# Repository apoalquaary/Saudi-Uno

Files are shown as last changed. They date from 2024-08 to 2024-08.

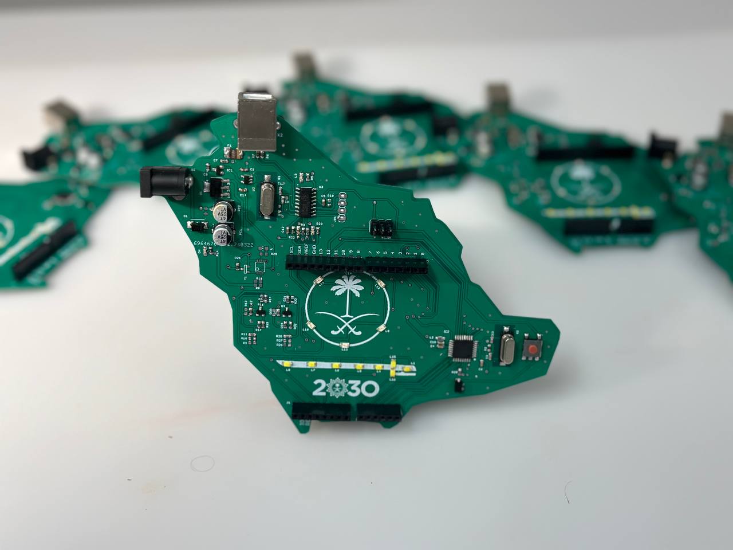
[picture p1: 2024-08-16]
images/photo_5908730412442698921_y.jpg

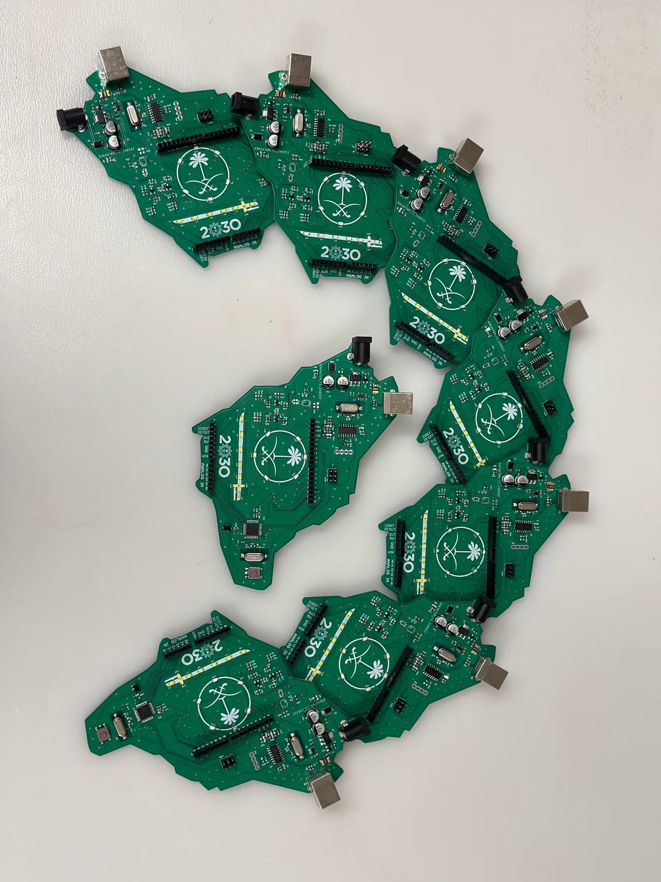
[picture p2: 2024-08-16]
images/photo_5908730412442698924_y.jpg

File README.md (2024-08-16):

<h1>Saudi UNO PCB Project</h1>
<p>This repository hosts the PCB design files for the Saudi UNO, an Arduino UNO-compatible device designed in the shape of the Saudi map. It's intended primarily for educational use in electronics and microcontroller programming.</p>

<h2>Project Overview</h2>
<p>The Saudi UNO is a unique Arduino UNO variant, customized to reflect the geographic outline of Saudi Arabia. It serves as an educational tool to engage students in learning about electronics design and practical PCB layout techniques.</p>

<h2>Files Included</h2>
<ul>
    <li><strong>Gerber Files:</strong> Contains all necessary manufacturing data for the PCB.</li>
    <li><strong>Schematic Files:</strong> Electronic schematics detailing component placement and connections.</li>
    <li><strong>Assembly Drawings:</strong> Helpful for visualizing component placement during the soldering process.</li>
    <li><strong>Bill of Materials (BOM):</strong> A comprehensive list of all components required to build the Saudi UNO.</li>
</ul>

<image src="https://github.com/apoalquaary/Saudi-Uno/blob/main/images/photo_5908730412442698918_y.jpg">
<image src="https://github.com/apoalquaary/Saudi-Uno/blob/main/images/photo_5908730412442698917_y.jpg">
<image src="https://github.com/apoalquaary/Saudi-Uno/blob/main/images/photo_5908730412442698921_y.jpg">
<image src="https://github.com/apoalquaary/Saudi-Uno/blob/main/images/photo_5908730412442698924_y.jpg">
<image src="https://github.com/apoalquaary/Saudi-Uno/blob/main/images/photo_5908730412442698913_y.jpg">

<h2>How to Use</h2>
<p>To use these files:</p>
<ol>
    <li>Download the desired files from the repository.</li>
    <li>Contact a PCB manufacturer and provide them with the Gerber files for production.</li>
    <li>Refer to the assembly drawings and BOM for assembling the PCB once manufactured.</li>
</ol>

<h2>Prerequisites</h2>
<p>You will need access to PCB manufacturing services and basic soldering tools to assemble the board. Familiarity with electronic components and soldering is recommended.</p>

<h2>Contributing</h2>
<p>If you have suggestions for improving the design, or have developed a variant of the Saudi UNO, please consider submitting a pull request. See <code>CONTRIBUTING.md</code> for more details on how to contribute.</p>

<h2>License</h2>
<p>This project is distributed under the Saudi UNO Non-Commercial License, which allows for non-commercial use such as academic and personal learning free of charge. Commercial use requires prior approval. For complete terms, see the <code>LICENSE</code> file.</p>

<h2>Contact</h2>
<p>For inquiries about commercial use or further questions, please reach out via [Your Email Address].</p>

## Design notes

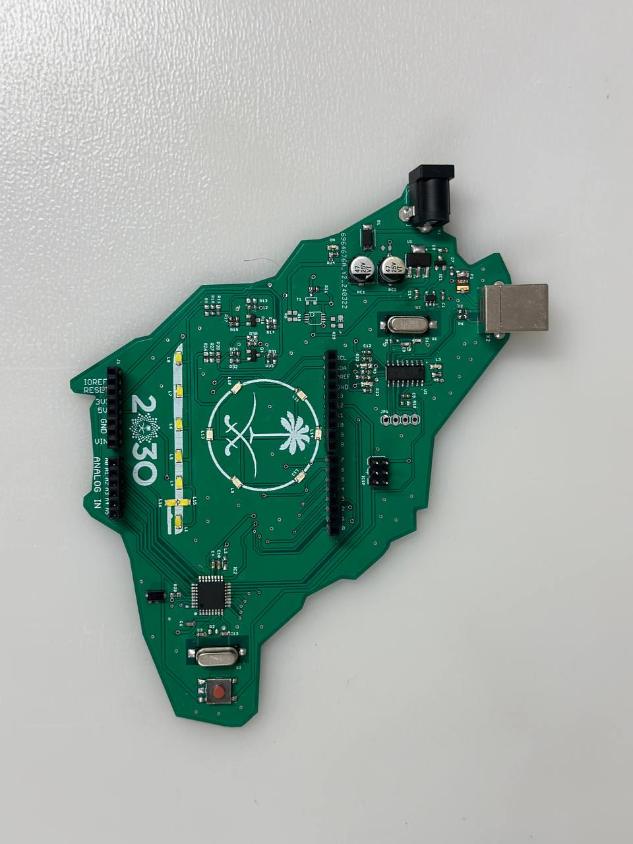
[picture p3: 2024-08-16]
images/photo_5908730412442698917_y.jpg

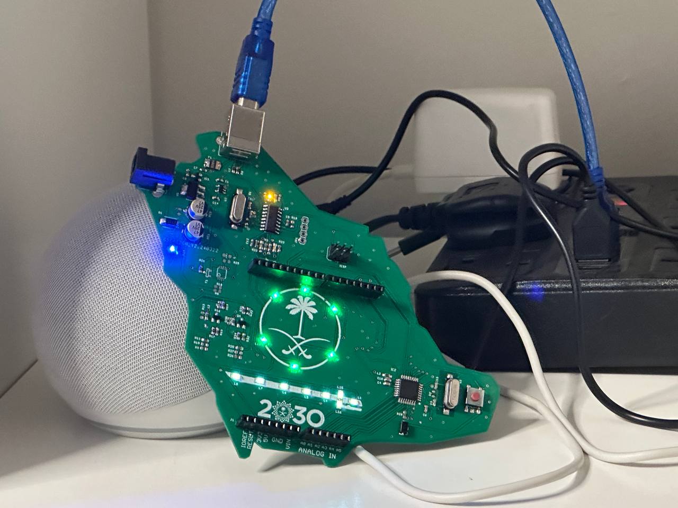
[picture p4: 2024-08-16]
images/photo_5908730412442698913_y.jpg

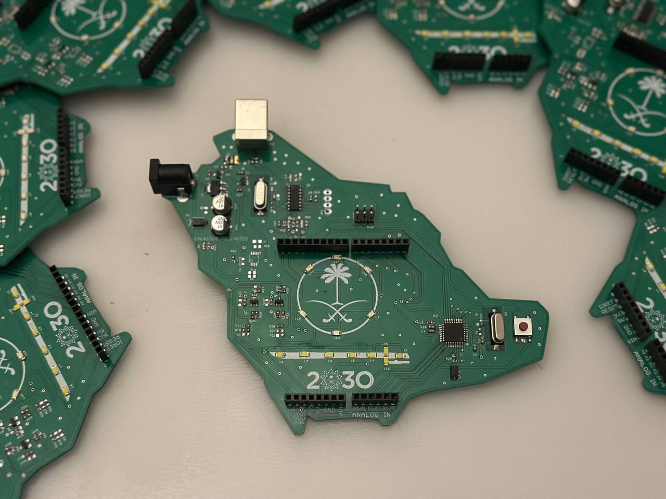
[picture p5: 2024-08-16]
images/photo_5908730412442698918_y.jpg

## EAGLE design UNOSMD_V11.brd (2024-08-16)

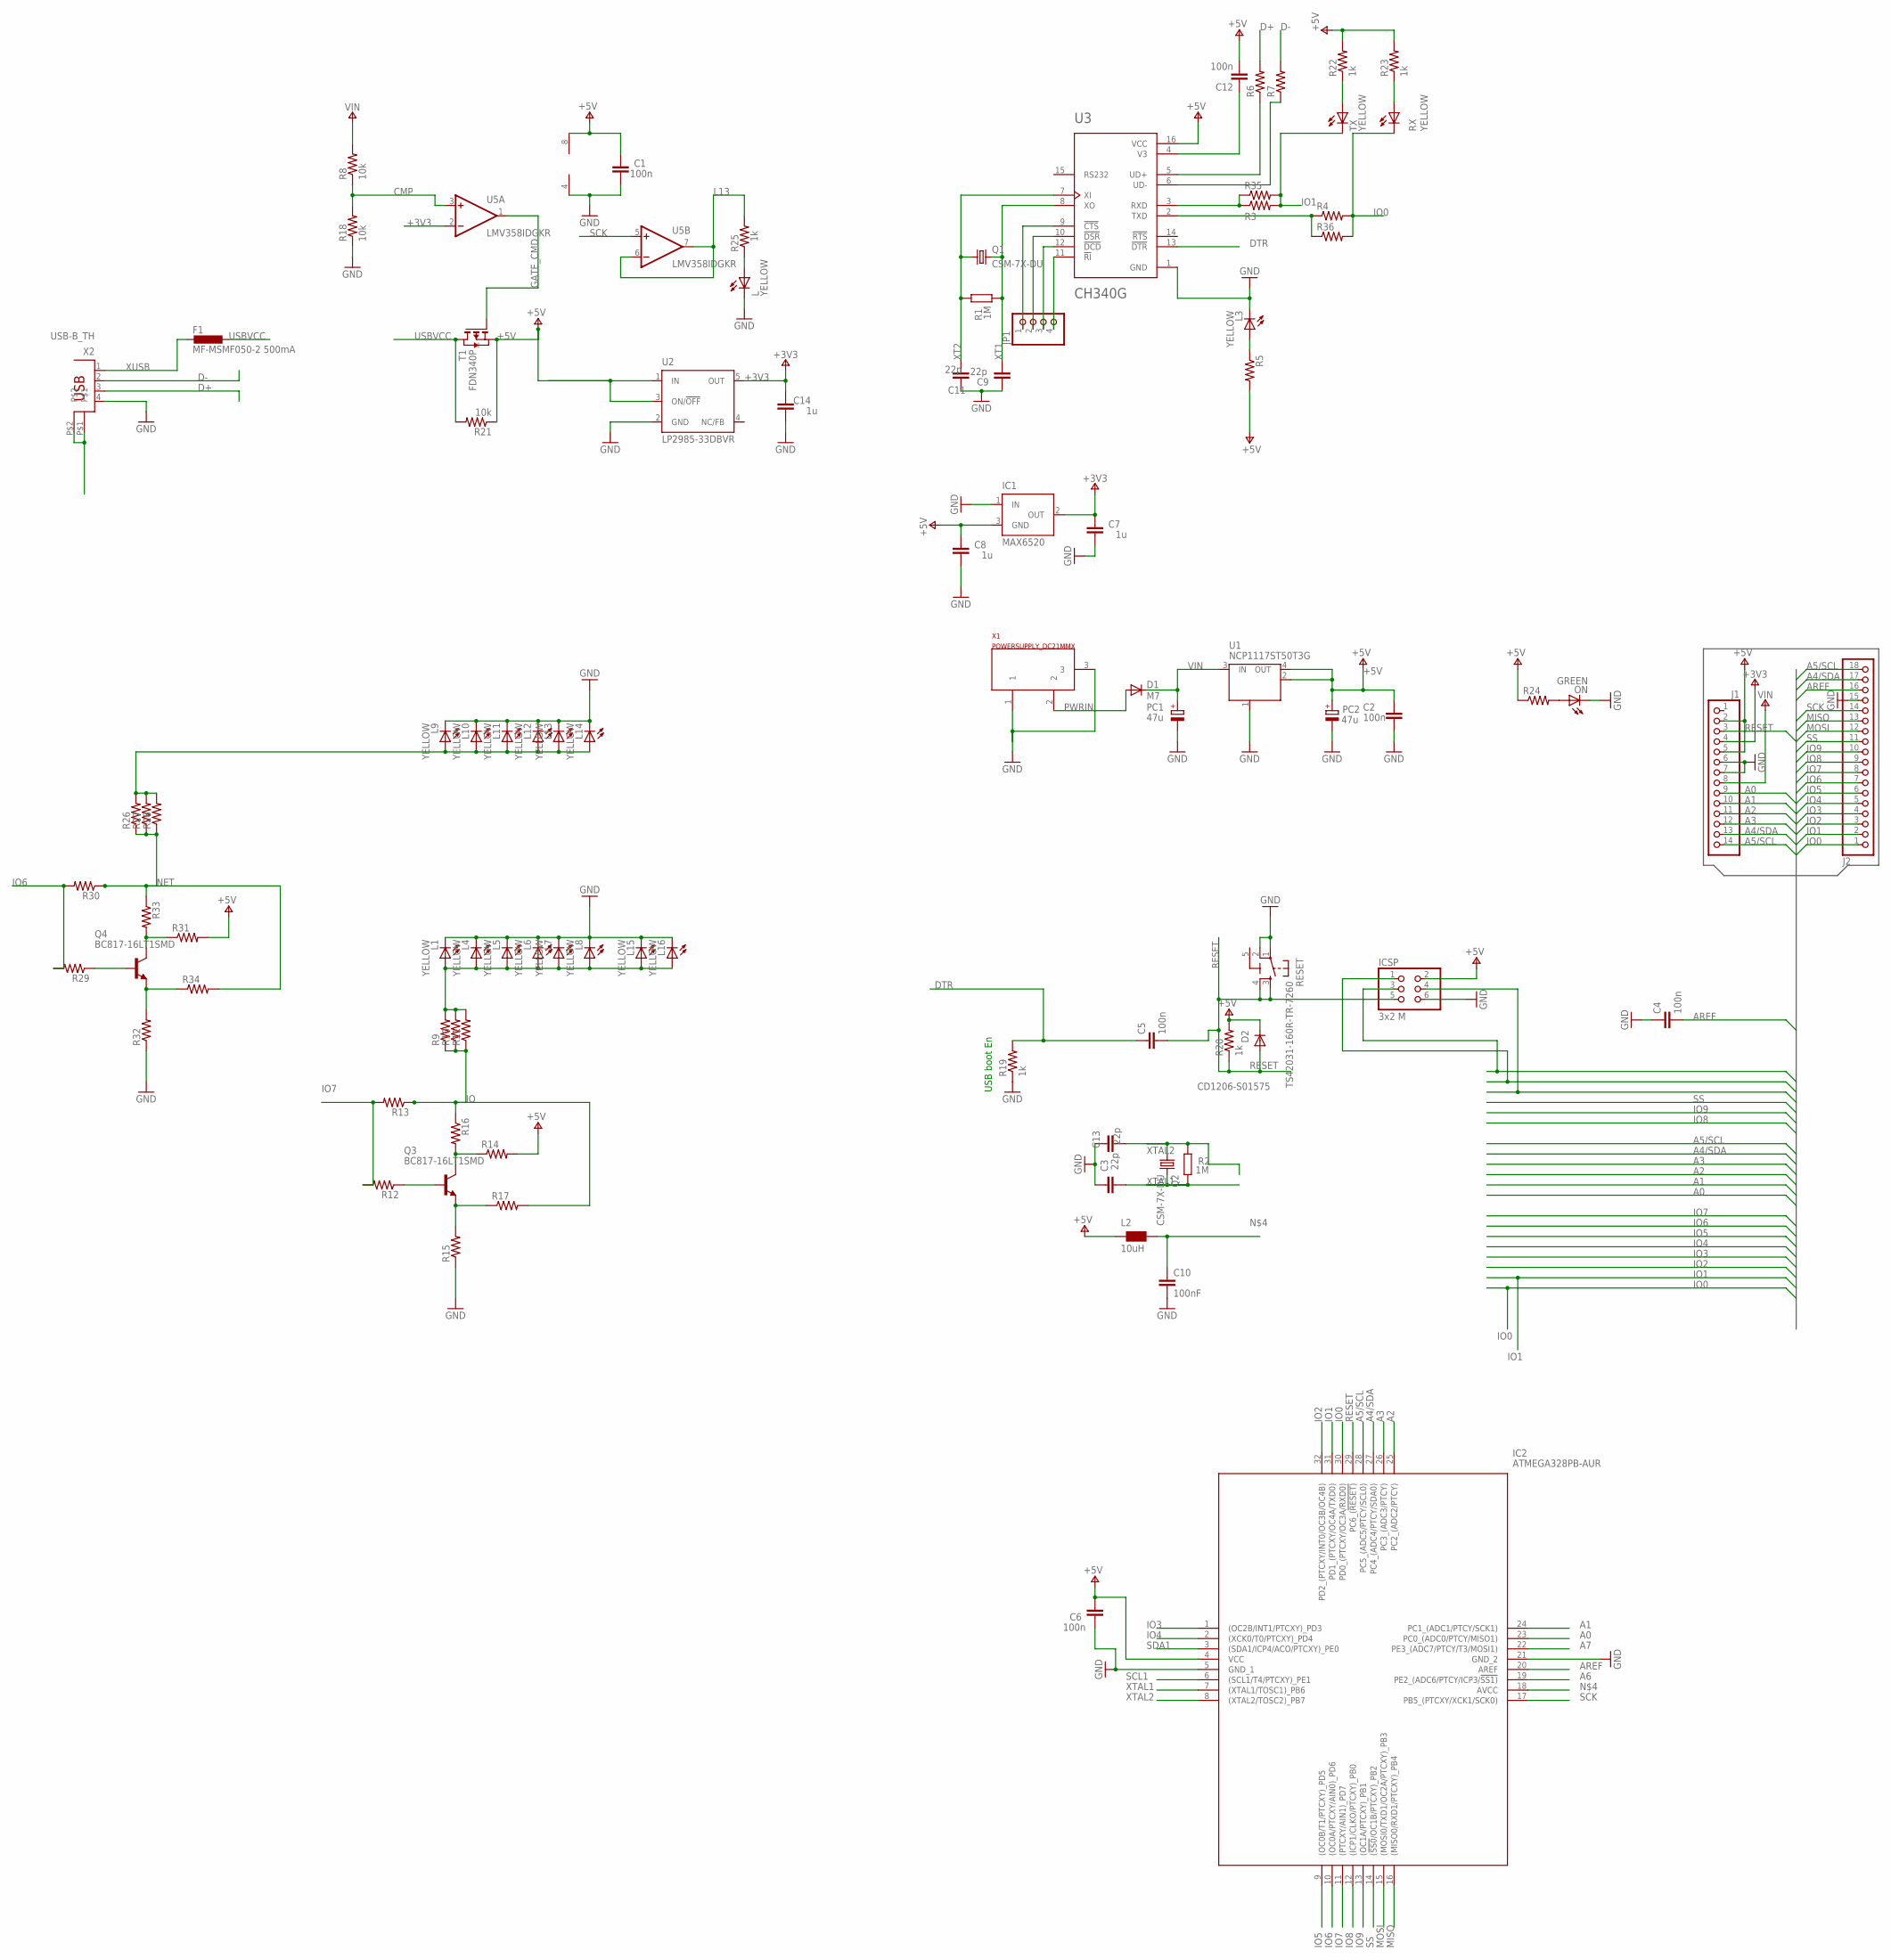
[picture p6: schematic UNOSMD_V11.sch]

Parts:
C1, C2, C4, C5, C6, C12: 100n; C0603-ROUND
C3, C9, C11, C13: 22p; C0603-ROUND
C7, C8, C14: 1u; C0603-ROUND
C10: 100nF; C0603-ROUND
D1: M7; SMB
D2: CD1206-S01575; MINIMELF
F1: MF-MSMF050-2 500mA; L1812
IC1: MAX6520; SOT23
IC2: ATMEGA328PB-AUR; QFP80P900X900X120-32N
ICSP: 3x2 M; 2X03
J1: -; 1X14-CUSTOM
J2: -; 1X18-CUSTOM
JP1: PINHD-1X4; 1X04
L, L1, L3, L4, L5, L6, L7, L8, L9, L10, L11, L12, L13, L14, L15, L16: YELLOW; CHIP-LED0805
L2: 10uH; 0805
ON: GREEN; CHIP-LED0805
PC1, PC2: 47u; PANASONIC_D
Q1, Q2: CSM-7X-DU
Q3, Q4: BC817-16LT1SMD; SOT23-BEC
R1, R2: 1M; R0603-ROUND
R3, R4, R5, R6, R7, R9, R10, R11, R12, R13, R14, R15, R16, R17, R24, R26, R27, R28, R29, R30, R31, R32, R33, R34, R35, R36: R-US_R0603; R0603
R8, R18, R21: 10k; R0603
R19, R20, R22, R23, R25: 1k; R0603
RESET: TS42031-160R-TR-7260; TS42
RX: YELLOW; CHIP-LED0805
T1: FDN340P; SOT-23
TX: YELLOW; CHIP-LED0805
U1: NCP1117ST50T3G; SOT223
U2: LP2985-33DBVR; SOT23-DBV
U3: CH340G; SOIC127P600X180-16N
U5: LMV358IDGKR; MSOP08
X1: POWERSUPPLY_DC21MMX; POWERSUPPLY_DC-21MM
X2: USB-B_TH; PN61729

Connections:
5-GND: RESET.5 (5-GND)
+3V3: C7.2, C14.2, IC1.2 (OUT), J1.4, U2.5 (OUT), U5.2 (-IN)
+5V: C1.2, C2.2, C6.2, C8.2, C12.2, D2.C, IC1.3 (GND), IC2.4 (VCC), ICSP.2, J1.2, J1.5, L2.1, PC2.+, R5.2, R14.2, R20.2, R21.1, R22.2, R23.2, R24.1, R31.2, T1.2 (S), U1.2 (OUT), U1.4 (OUT), U2.1 (IN), U2.3 (ON/!OFF), U3.16 (VCC), U5.8 (V+)
A0: IC2.23 (PC0_(ADC0/PTCY/MISO1)), J1.9
A1: IC2.24 (PC1_(ADC1/PTCY/SCK1)), J1.10
A2: IC2.25 (PC2_(ADC2/PTCY)), J1.11
A3: IC2.26 (PC3_(ADC3/PTCY)), J1.12
A4/SDA: IC2.27 (PC4_(ADC4/PTCY/SDA0)), J1.13, J2.17
A5/SCL: IC2.28 (PC5_(ADC5/PTCY/SCL0)), J1.14, J2.18
A6: IC2.19 (PE2_(ADC6/PTCY/ICP3/!SS1))
A7: IC2.22 (PE3_(ADC7/PTCY/T3/MOSI1))
AREF: C4.2, IC2.20 (AREF), J2.16
CMP: R8.1, R18.2, U5.3 (+IN)
D+: R6.2, X2.3
D-: R7.2, X2.2
DTR: C5.1, R19.2, U3.13 (!DTR)
GATE_CMD: T1.3 (G), U5.1 (OUT)
GND: C1.1, C2.1, C3.2, C4.1, C6.1, C7.1, C8.1, C9.2, C10.2, C11.2, C13.2, C14.1, IC1.1 (IN), IC2.5 (GND_1), IC2.21 (GND_2), ICSP.6, J1.6, J1.7, J2.15, L.C, L1.C, L3.C, L4.C, L5.C, L6.C, L7.C, L8.C, L9.C, L10.C, L11.C, L12.C, L13.C, L14.C, L15.C, L16.C, ON.C, PC1.-, PC2.-, R15.1, R18.1, R19.1, R32.1, RESET.1, RESET.2, U1.1 (GND/ADJ), U2.2 (GND), U3.1 (GND), U5.4 (V-), X1.1, X1.3, X2.4
IO: R9.1, R10.1, R11.1, R13.1, R16.1, R17.2
IO0: IC2.30 (PD0_(PTCXY/OC3A/RXD0)), J2.1, R4.2, R36.2, RX.C
IO1: IC2.31 (PD1_(PTCXY/OC4A/TXD0)), J2.2, R3.2, R35.2, TX.C
IO2: IC2.32 (PD2_(PTCXY/INT0/OC3B/OC4B)), J2.3
IO3: IC2.1 ((OC2B/INT1/PTCXY)_PD3), J2.4
IO4: IC2.2 ((XCK0/T0/PTCXY)_PD4), J2.5
IO5: IC2.9 ((OC0B/T1/PTCXY)_PD5), J2.6
IO6: IC2.10 ((OC0A/PTCXY/AIN0)_PD6), J2.7, R29.2, R30.2
IO7: IC2.11 ((PTCXY/AIN1)_PD7), J2.8, R12.2, R13.2
IO8: IC2.12 ((ICP1/CLKO/PTCXY)_PB0), J2.9
IO9: IC2.13 ((OC1A/PTCXY)_PB1), J2.10
L13: R25.2, U5.6 (-IN), U5.7 (OUT)
MISO: IC2.16 ((MISO0/RXD1/PTCXY)_PB4), ICSP.1, J2.13
MOSI: IC2.15 ((MOSI0/TXD1/OC2A/PTCXY)_PB3), ICSP.4, J2.12
unnamed: ON.A, R24.2
unnamed: R3.1, R35.1, U3.3 (RXD)
unnamed: C10.1, IC2.18 (AVCC), L2.2
unnamed: R4.1, R36.1, U3.2 (TXD)
unnamed: C12.1, U3.4 (V3)
unnamed: L3.A, R5.1
unnamed: R6.1, U3.5 (UD+)
unnamed: R7.1, U3.6 (UD-)
unnamed: L.A, R25.1
unnamed: Q3.B, R12.1
unnamed: JP1.1, U3.9 (!CTS)
unnamed: Q3.E, R15.2, R17.1
unnamed: Q3.C, R14.1, R16.2
unnamed: JP1.2, U3.10 (!DSR)
unnamed: JP1.3, U3.12 (!DCD)
unnamed: JP1.4, U3.11 (!RI)
unnamed: L1.A, L4.A, L5.A, L6.A, L7.A, L8.A, L15.A, L16.A, R9.2, R10.2, R11.2
unnamed: Q4.B, R29.1
unnamed: Q4.E, R32.2, R34.1
unnamed: Q4.C, R31.1, R33.2
unnamed: L9.A, L10.A, L11.A, L12.A, L13.A, L14.A, R26.2, R27.2, R28.2
unnamed: R23.1, RX.A
unnamed: R22.1, TX.A
NET: R26.1, R27.1, R28.1, R30.1, R33.1, R34.2
PWRIN: D1.A, X1.2
RESET: C5.2, D2.A, IC2.29 (PC6_(!RESET)), ICSP.5, J1.3, R20.1, RESET.3, RESET.4
SCK: IC2.17 (PB5_(PTCXY/XCK1/SCK0)), ICSP.3, J2.14, U5.5 (+IN)
SCL1: IC2.6 ((SCL1/T4/PTCXY)_PE1)
SDA1: IC2.3 ((SDA1/ICP4/ACO/PTCXY)_PE0)
SS: IC2.14 ((!SS0!/OC1B/PTCXY)_PB2), J2.11
USBVCC: F1.1, R21.2, T1.1 (D)
USHIELD: X2.P$1, X2.P$2
VIN: D1.C, J1.8, PC1.+, R8.2, U1.3 (IN)
XT1: C9.1, Q1.2, R1.1, U3.8 (XO)
XT2: C11.1, Q1.1, R1.2, U3.7 (XI)
XTAL1: C3.1, IC2.7 ((XTAL1/TOSC1)_PB6), Q2.2, R2.1
XTAL2: C13.1, IC2.8 ((XTAL2/TOSC2)_PB7), Q2.1, R2.2
XUSB: F1.2, X2.1

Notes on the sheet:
USB boot En

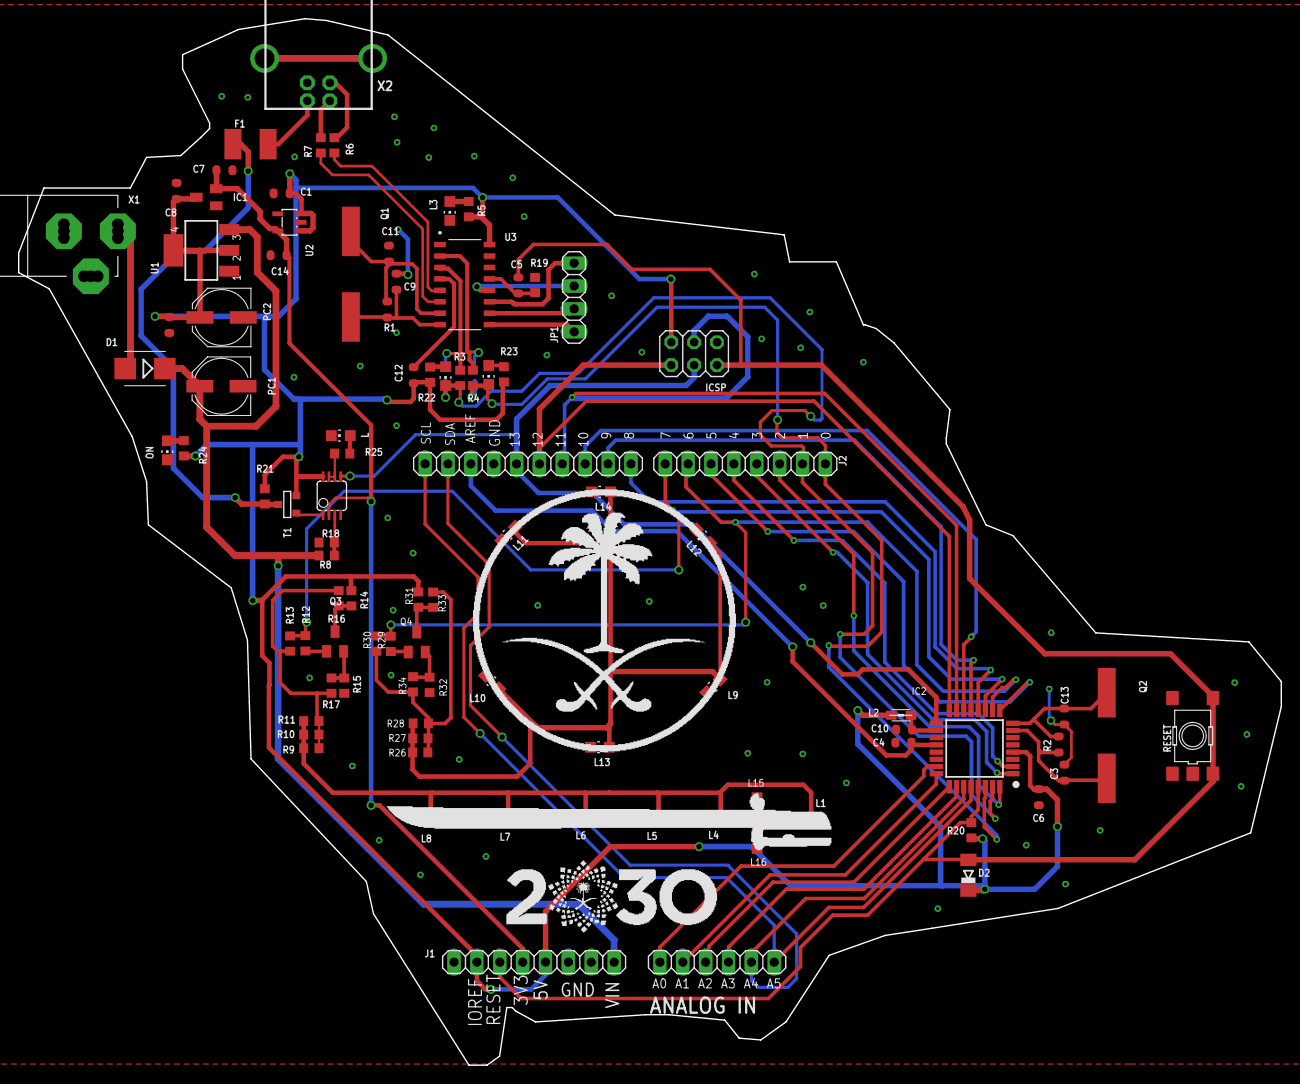
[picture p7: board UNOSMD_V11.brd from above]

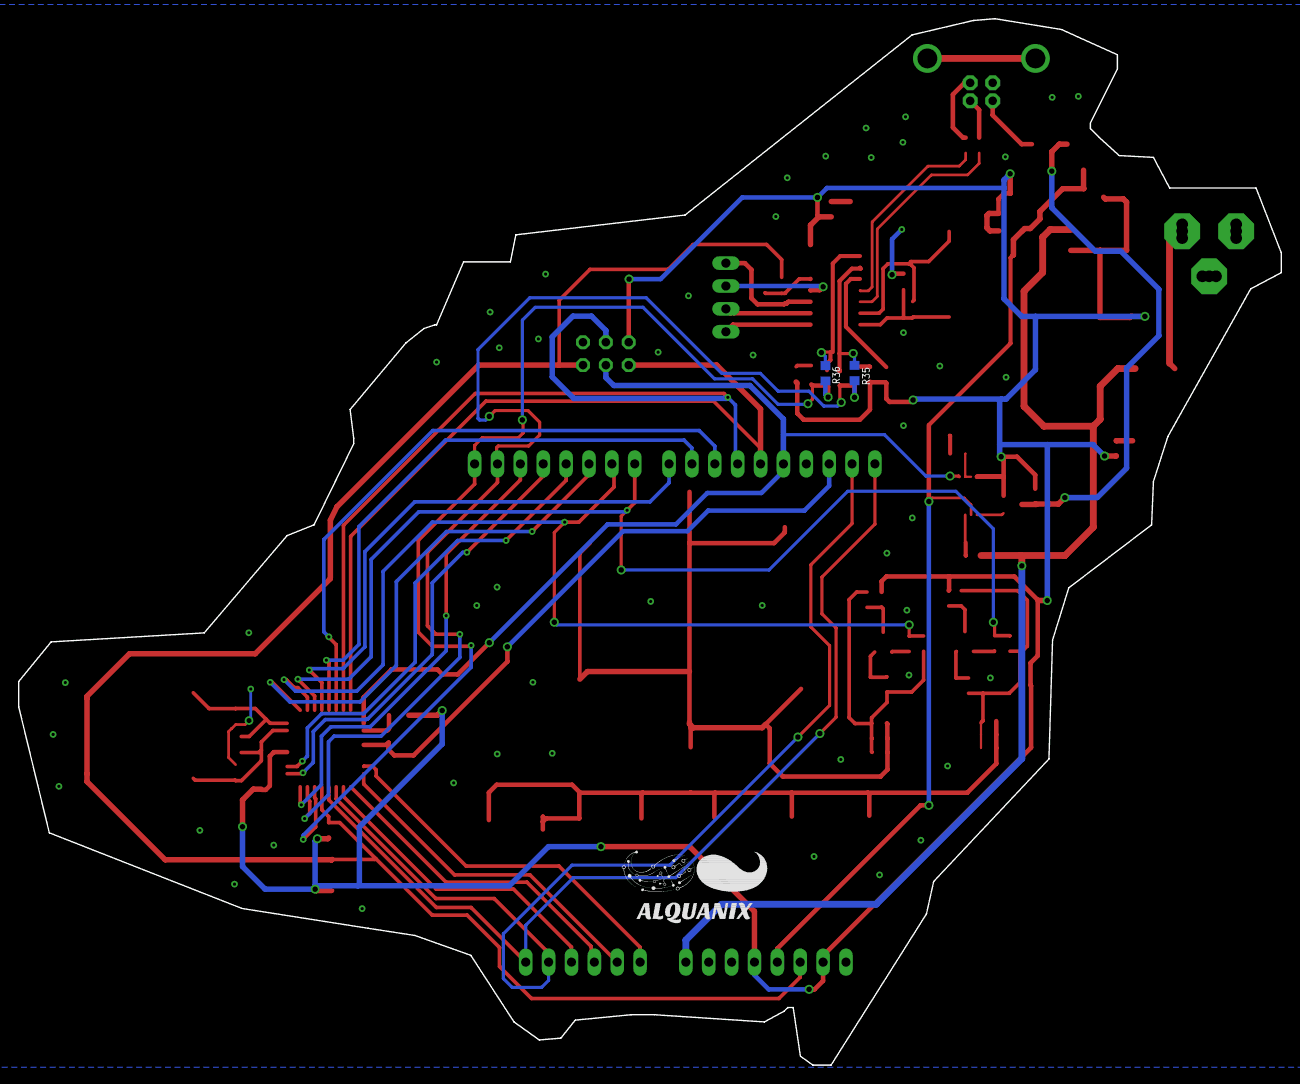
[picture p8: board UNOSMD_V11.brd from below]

Board: 2 copper layers, 140.2 x 116.2 mm, 93 parts (2 on the bottom side), 65 nets.

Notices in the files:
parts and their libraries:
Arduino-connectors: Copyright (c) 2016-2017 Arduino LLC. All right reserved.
